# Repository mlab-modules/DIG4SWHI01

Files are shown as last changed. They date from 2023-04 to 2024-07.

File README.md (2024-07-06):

# DIG4SWHI01A - quad channel current sensing high-side switch

Switch for voltage from 4 V to 28 V. Resistance in spliced state 50 mOhm. Integrated circuit [VNQ7050AJ](https://www.st.com/en/automotive-analog-and-power/vnq7050aj.html).

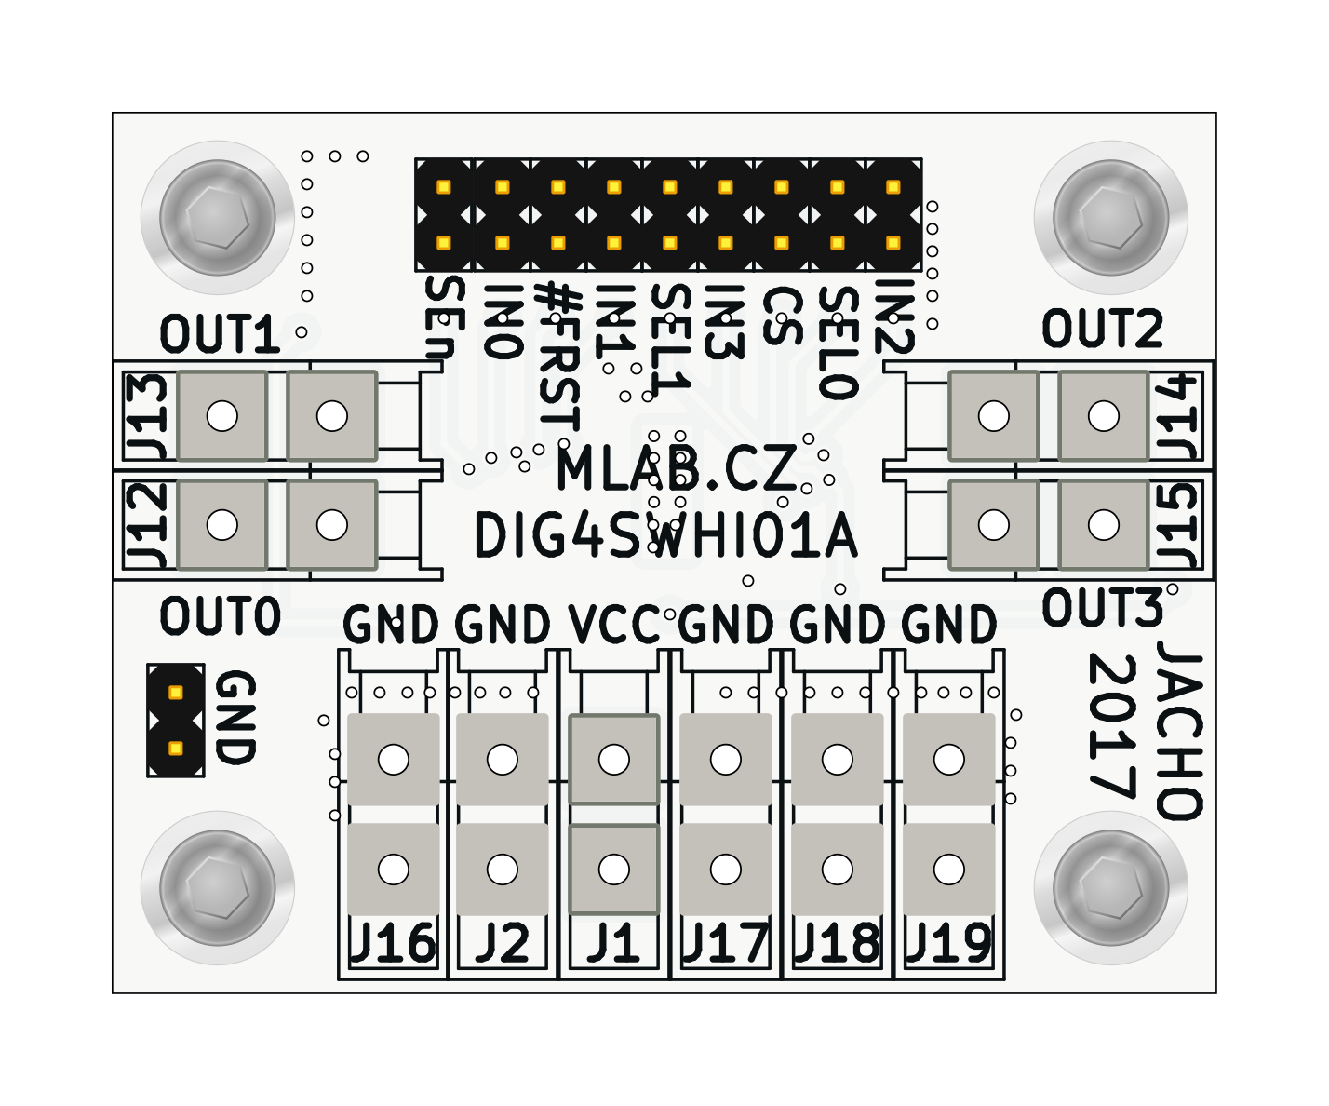
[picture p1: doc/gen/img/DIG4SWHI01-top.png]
DIG4SWHI01A

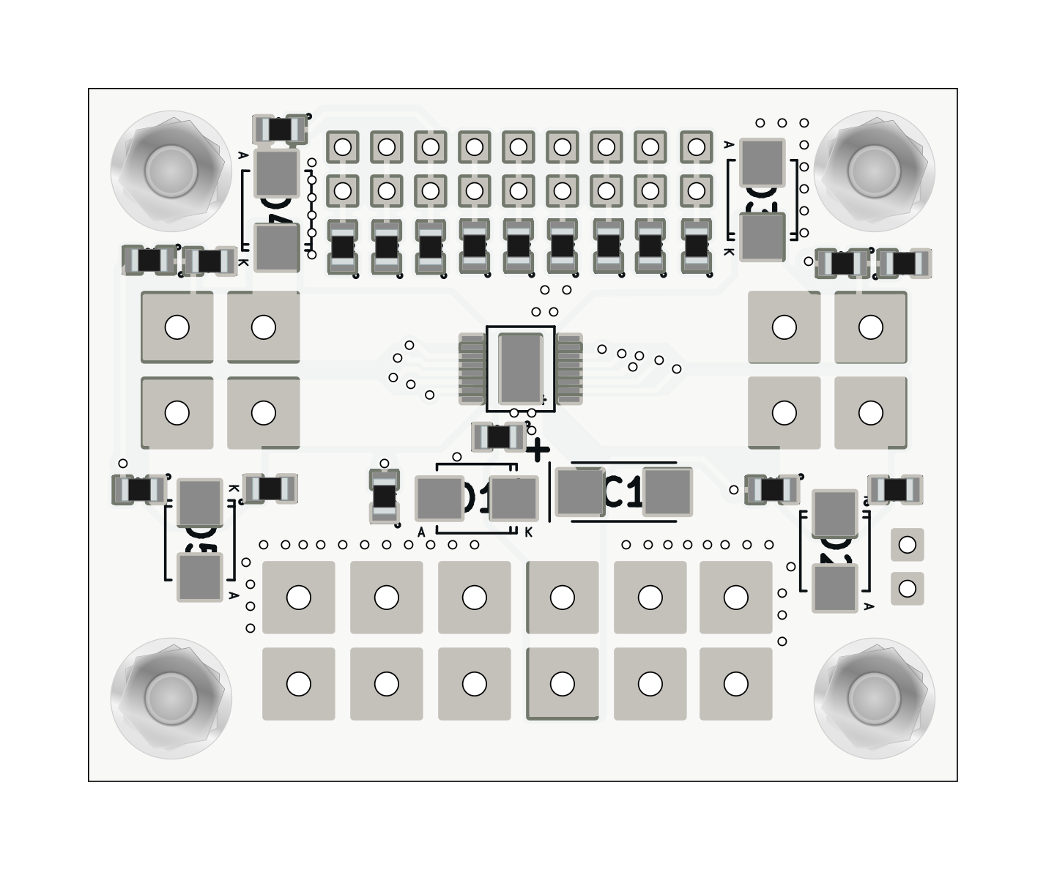
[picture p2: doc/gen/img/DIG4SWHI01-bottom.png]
DIG4SWHI01A


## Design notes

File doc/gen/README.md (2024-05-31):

# PCB

Board size: 50.29x40.13 mm (1.98x1.58 inches)

- This is the size of the rectangle that contains the board
- Thickness: 1.6 mm (63 mils)
- Material: FR4
- Finish: HAL
- Layers: 2
- Copper thickness: 35 µm

Solder mask: TOP / BOTTOM

- Color: Green

Silk screen: TOP / BOTTOM

- Color: White

# Important sizes

Clearance: 0.2 mm (8 mils)

Track width: 0.25 mm (10 mils)

- By design rules: 0.2 mm (8 mils)

Drill: 0.5 mm (20 mils)

- Vias: 0.5 mm (20 mils) [Design: 0.4 mm (16 mils)]
- Pads: 0.5 mm (20 mils)
- The above values are real drill sizes, they add 0.1 mm (4 mils) to plated holes (PTH)

Via: 0.8/0.4 mm (31/16 mils)

- By design rules: 0.4/0.3 mm (16/12 mils)
- Micro via: yes [0.2/0.1 mm (8/4 mils)]
- Buried/blind via: yes
- Total: 74 (thru: 74 buried/blind: 0 micro: 0)

Outer Annular Ring: 0.15 mm (6 mils)

- By design rules: 0.26 mm (10 mils)

Eurocircuits class: 4B
- Using min drill 0.5 mm for an OAR of 0.15 mm

# General stats

Components count: (SMD/THT)

- Top: 0/24 (THT)
- Bottom: 26/1 (SMD + THT)

Defined tracks:

- 0.3 mm (12 mils)
- 0.4 mm (16 mils)
- 0.5 mm (20 mils)
- 0.6 mm (24 mils)
- 0.8 mm (31 mils)
- 1.0 mm (39 mils)

Used tracks:

- 0.25 mm (10 mils) (76) defined: no
- 0.3 mm (12 mils) (139) defined: yes

Defined vias:

Used vias:

- 0.8/0.4 mm (31/16 mils) (Count: 74, Aspect: 2.0 A) defined: no

Holes (excluding vias):

- 0.4 mm (16 mils) (8)
- 0.89 mm (35 mils) (20)
- 1.3 mm (51 mils) (20)
- 3.0 mm (118 mils) (4)

Oval holes:

Drill tools (including vias and computing adjusts and rounding):

- 0.5 mm (20 mils) (82)
- 1.0 mm (39 mils) (20)
- 1.4 mm (55 mils) (20)
- 3.1 mm (122 mils) (4)

Solder paste stats:

Using a paste with 87.75 % alloy, that has an specific gravity for the alloy of 7.4 g/cm³
and 1.0 g/cm³ for the flux. This paste has an specific gravity of  4.15 g/cm³.

The stencil thickness is  0.12 mm.

| Side | Pads with paste | Area [mm²] | Paste [g] |
|---|---|---|---|
| Total  | 69 | 134.06 | 0.67 |

Note: this is just an approximation to the theoretical value. Margins of the solder mask and waste aren't computed.

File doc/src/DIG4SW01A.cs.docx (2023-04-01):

Plný H-můstek s proudovou ochranou

Jan Chroust

## Základem modulu je integrovaný obvod DRV8871, který umožňuje řízení zátěže špičkově až do 3,6 A při napětích v rozsahu 6,5 V – 45 V. Externím odporem je možné nastavit maximální proud.

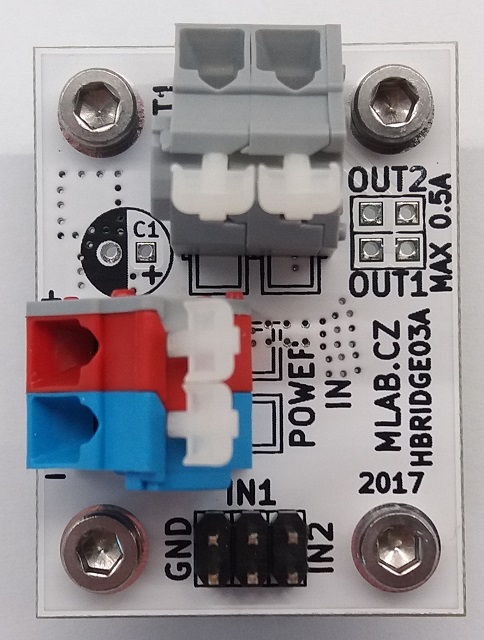
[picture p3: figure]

# 1. Technické parametry

Parametr | Hodnota | Poznámka
Napájení | 6,5 V – 45 V
Proud | Max 3,6A | Špičkově
Integrovaný obvod | DRV8871
Hlavní využití | H-můstek
Rozměry | 40.13 x 30.00 x 16 mm | Výška nad základní deskou

# 2. Popis konstrukce

Modul je napájen přes Wago svorky označené POWER IN. Pro zapojení zátěže je možné si vybrat mezi svorkovnicí Wago, nebo hřebínkem. Při využití hřebínku by zátěž neměla překročit odběr 0,5 A.

Rezistorem R1 je možné provést nastavení maximálního proudu.

I_(MAX) =64/(R1 (kOhm)) (A)

Ovládání režimu můstku se provádí přes piny IN1 a IN2. Odpory R2 a R3 tvoří pull-down pro tyto vstupy. IO obsahuje vnitřní pull-down rezistory, proto tyto pozice není potřeba standardně osazovat.

Tabulka režimů:

IN1 | IN2 | OUT1 | OUT2
0 | 0 | Vysoká Z | Vysoká Z | Po 1ms spánkový režim
0 | 1 | L | H | I OUT2->OUT1
1 | 0 | H | L | I OUT1->OUT2
1 | 1 | L | L | Brždění

## 2.1. Schéma

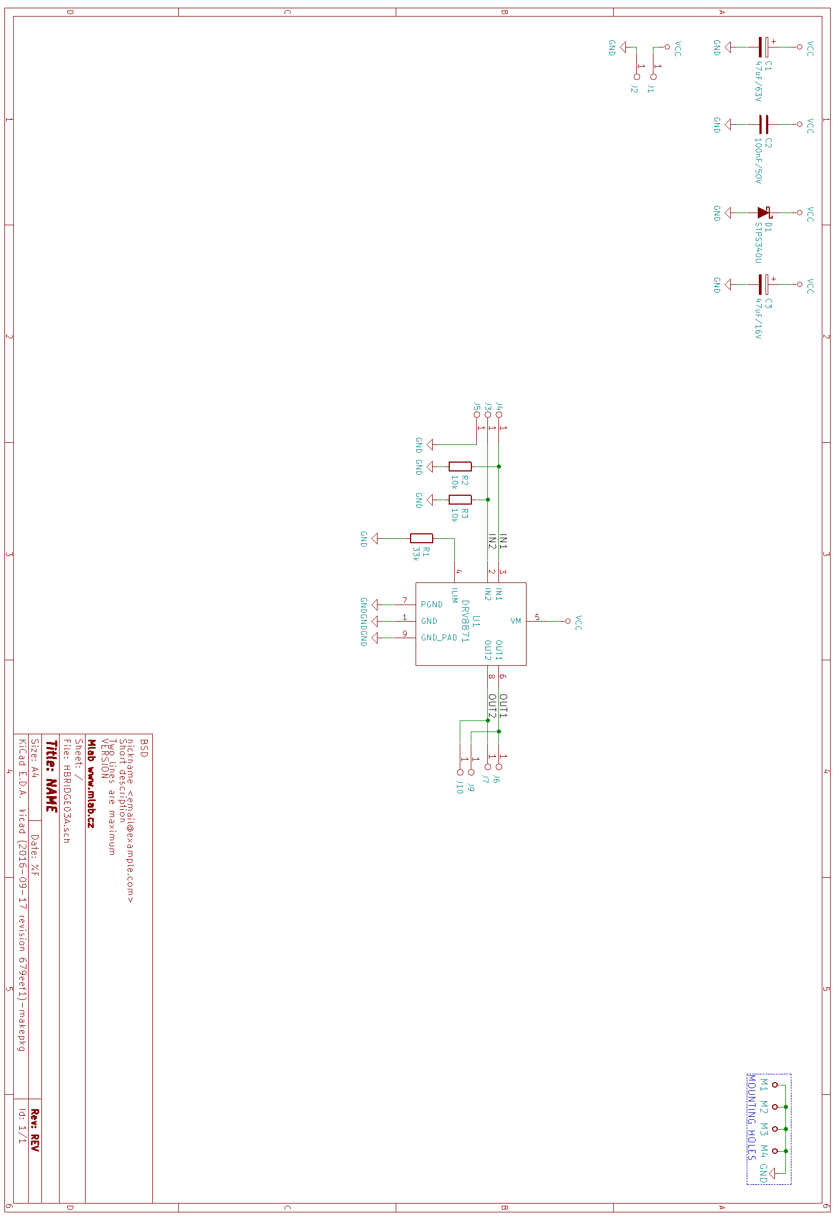
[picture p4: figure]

# 3. Osazení a oživení

## 3.1. Osazení

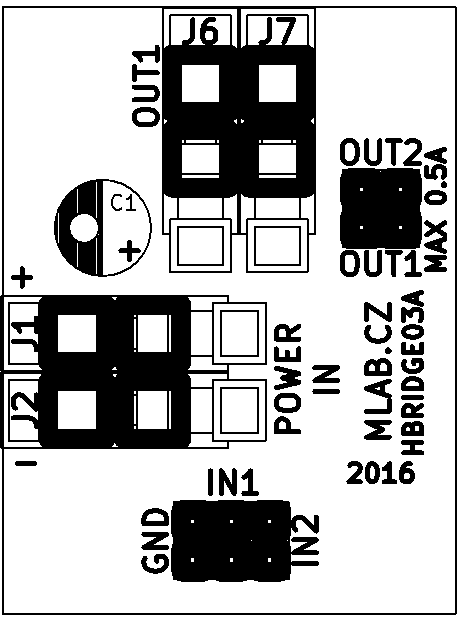
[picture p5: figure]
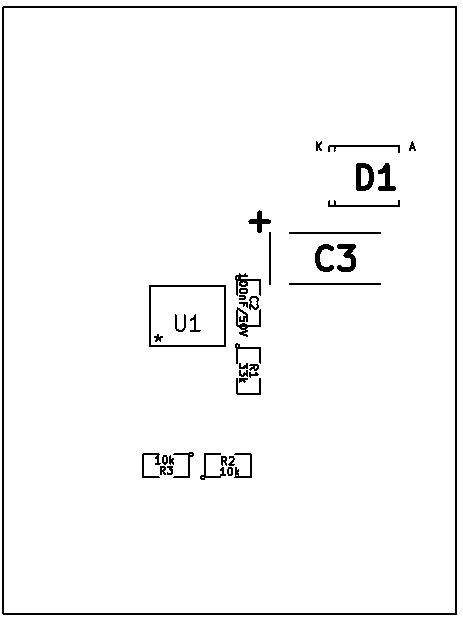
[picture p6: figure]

Označení | Typ | Pouzdro | Počet
U1 | DRV8871 | HSOP-8 | 1
C2 | 100nF/50V | SMD-0805 | 1
C3 | 47uF/16V | TantalC_SizeC_Reflow | 1
D1 | STPS340U | Diode-SMB_Standard | 1
J1,J2,J6,J7 | CONN1_1 | WAGO256 | 4
J3,J4,J5,J9,J10 | JUMP_2x1 | Straight_2x01 | 5
M1,M2,M3,M4 | HOLE | MountingHole_3mm | 4
R1 | 33k | SMD-0805 | 1
C1 | 47uF/63V | C_Radial_D6.3_L11.2_P2.5 | 1
R2,R3 | nic | SMD-0805 | 2

## 3.2. Oživení

Po osazení modulu je dobré provést vizuální kontrolu, případně proměřit, zda na napájení není zkrat. Další oživení není potřeba.

HBRIDGE03A / 2017-05-09 / jacho/ http://www.mlab.cz 4 / 4

HBRIDGE03A MLAB

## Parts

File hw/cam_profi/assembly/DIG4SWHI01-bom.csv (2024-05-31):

Component | Description | Part | References | Value | Footprint | Quantity Per PCB | Datasheet
1 |  | C | C3 | 100pF | SMD-0805 | 1
2 |  | C | C4C5C6C7 | 10nF | SMD-0805 | 4
3 |  | C | C2 | 100nF | SMD-0805 | 1
4 |  | CP | C1 | 47uF/16V | TantalC_SizeC_Reflow | 1
5 |  | D_Schottky | D1 | SMBJ15A-E3/52 | Diode-SMB_Standard | 1
6 |  | D_ZENER | D2D3D4D5 | SMBJ15A-E3/52 | SMB_Standard | 4
7 |  | CONN1_1 | J1J2J12J13J14J15J16J17J18J19 | CONN1_1 | WAGO256_2 | 10
8 |  | JUMP_2x1 | J3J4J5J6J7J8J9J10J11J20 | JUMP_2x1 | Straight_2x01 | 10
9 |  | R | R2 | 510 | SMD-0805 | 1
10 |  | R | R1R3R4R5R6R7R8R9R10 | 10k | SMD-0805 | 9
11 |  | R | R11R12R13R14 | 20k | SMD-0805 | 4
12 |  | VNQ7050AJ | U1 | VNQ7050AJ | PowerSSO-16 | 1

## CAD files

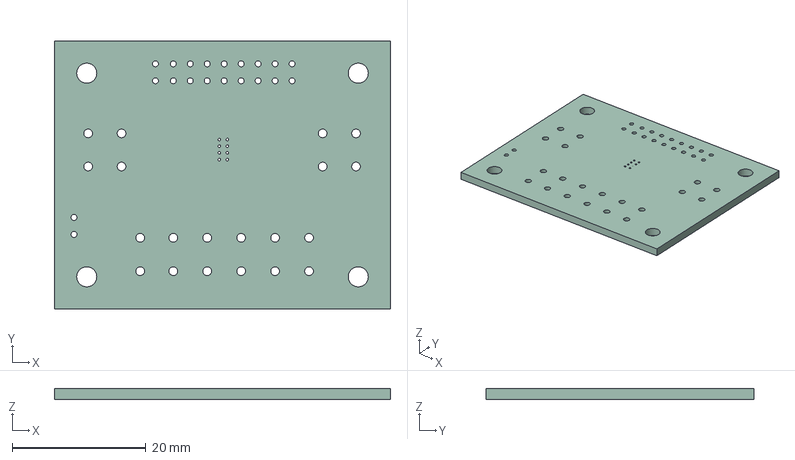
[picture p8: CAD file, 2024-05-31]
doc/gen/DIG4SWHI01.step
50.3 x 40.1 x 1.60 mm

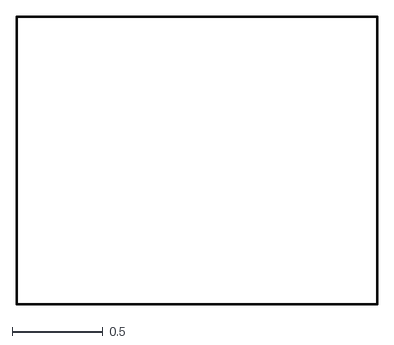
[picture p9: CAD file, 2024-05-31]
doc/gen/dxf/DIG4SWHI01-Edge_Cuts.dxf
1.99 x 1.59

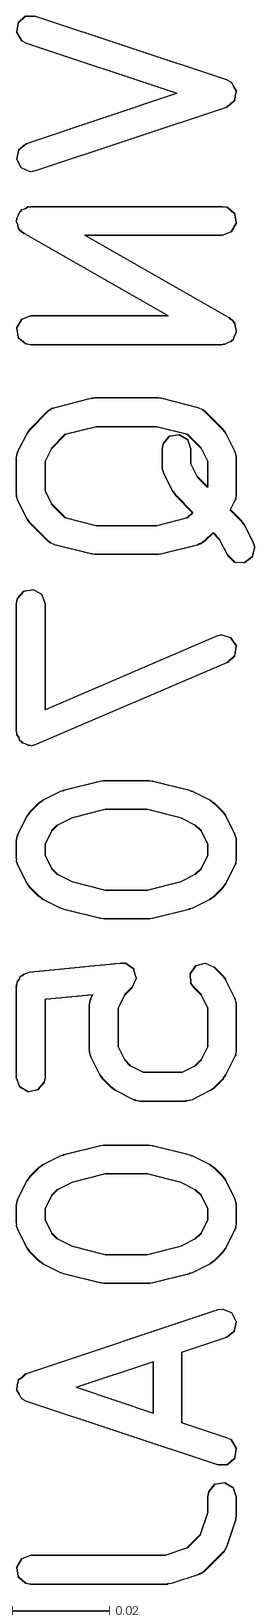
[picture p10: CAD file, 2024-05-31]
doc/gen/dxf/DIG4SWHI01-B_Fab.dxf
0.049 x 0.323

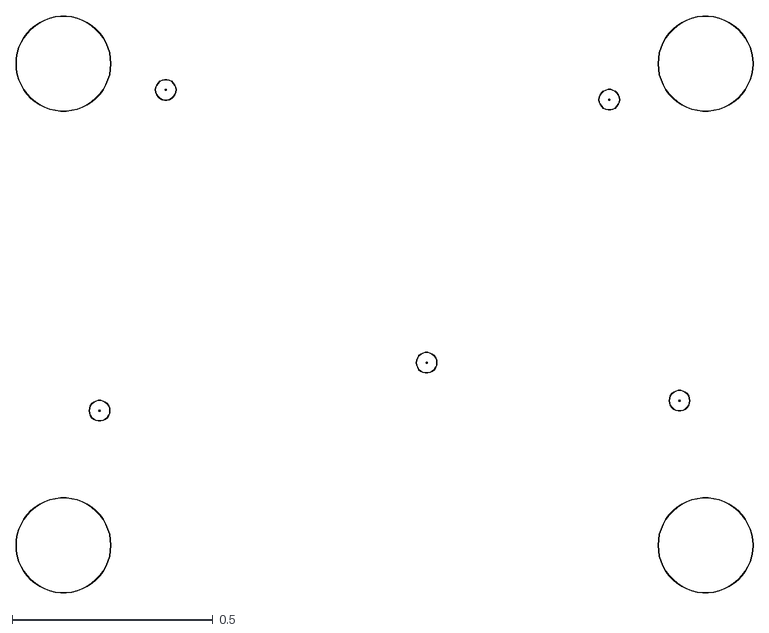
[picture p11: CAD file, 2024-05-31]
doc/gen/dxf/DIG4SWHI01-B_Adhesive.dxf
1.84 x 1.44

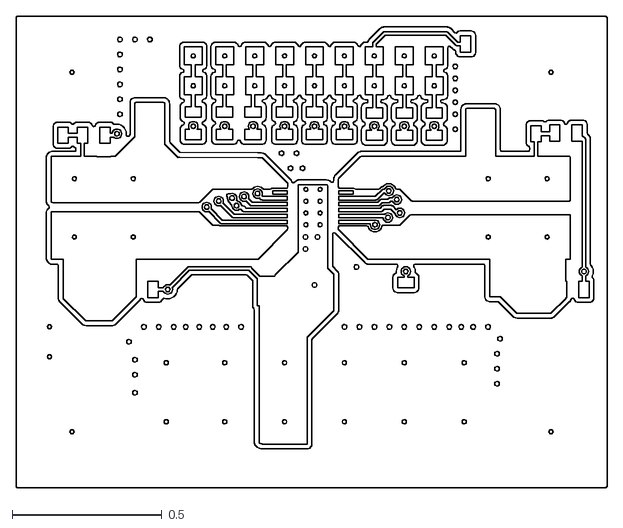
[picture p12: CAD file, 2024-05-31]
doc/gen/dxf/DIG4SWHI01-B_Cu.dxf
1.97 x 1.57

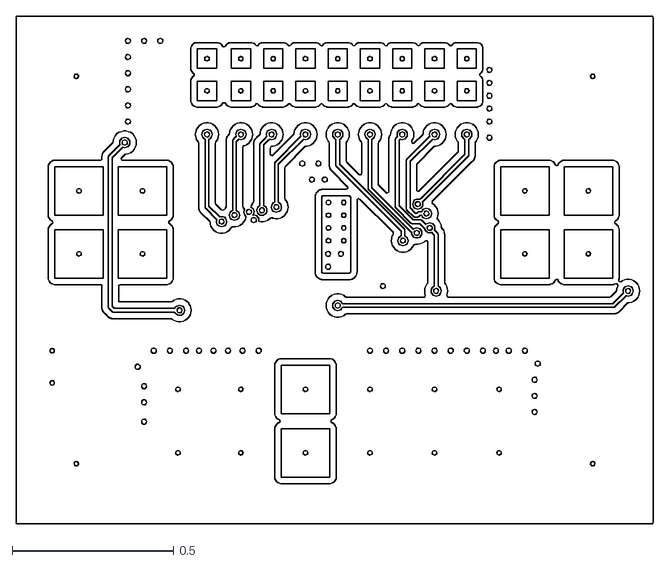
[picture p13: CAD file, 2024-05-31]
doc/gen/dxf/DIG4SWHI01-F_Cu.dxf
1.97 x 1.57

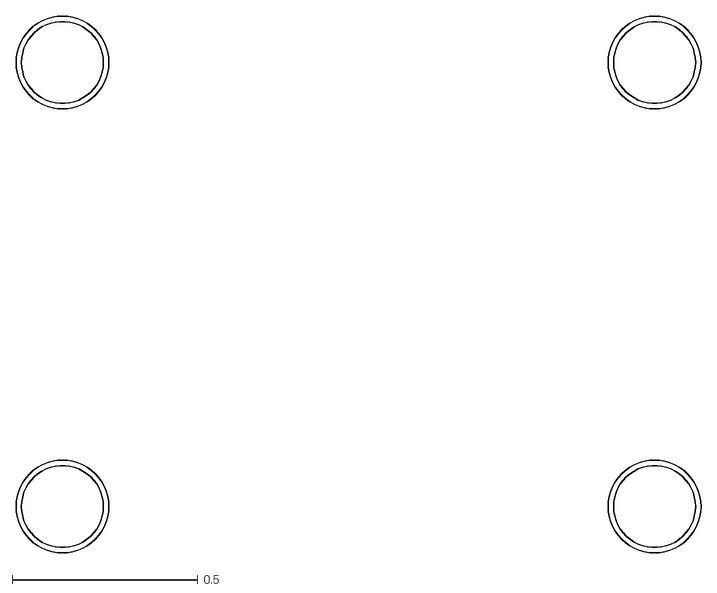
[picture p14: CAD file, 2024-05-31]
doc/gen/dxf/DIG4SWHI01-User_Comments.dxf
1.85 x 1.45

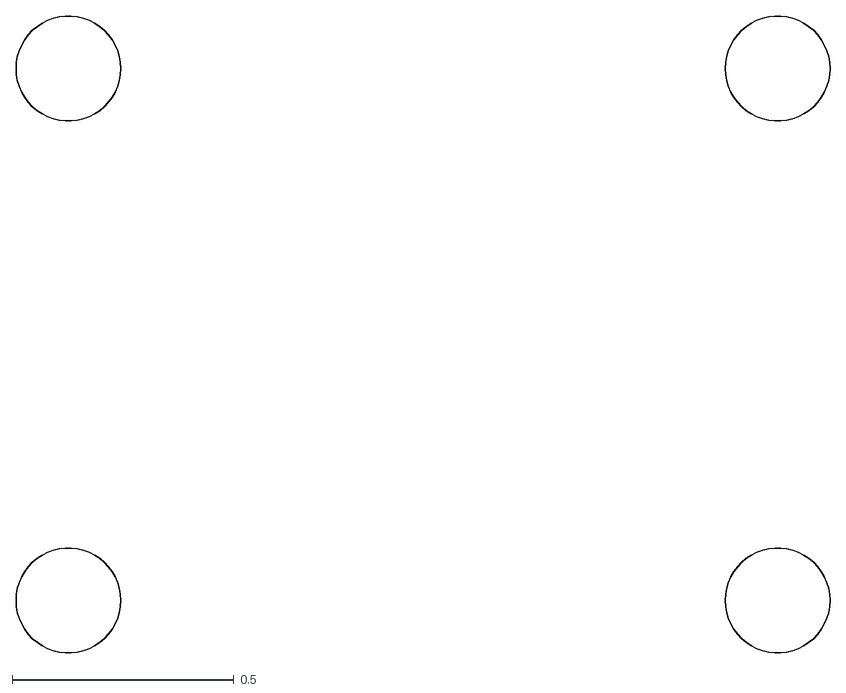
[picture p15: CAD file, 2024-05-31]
doc/gen/dxf/DIG4SWHI01-F_Adhesive.dxf
1.84 x 1.44

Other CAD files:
doc/gen/dxf/DIG4SWHI01-B_Courtyard.dxf
doc/gen/dxf/DIG4SWHI01-F_Fab.dxf
doc/gen/dxf/DIG4SWHI01-User_Eco1.dxf
doc/gen/dxf/DIG4SWHI01-User_Drawings.dxf
doc/gen/dxf/DIG4SWHI01-User_Eco2.dxf
doc/gen/dxf/DIG4SWHI01-Margin.dxf
doc/gen/dxf/DIG4SWHI01-F_Courtyard.dxf
doc/gen/dxf/DIG4SWHI01-B_Mask.dxf
doc/gen/dxf/DIG4SWHI01-B_Paste.dxf
doc/gen/dxf/DIG4SWHI01-B_Silkscreen.dxf
doc/gen/dxf/DIG4SWHI01-F_Mask.dxf
doc/gen/dxf/DIG4SWHI01-F_Paste.dxf
doc/gen/dxf/DIG4SWHI01-F_Silkscreen.dxf

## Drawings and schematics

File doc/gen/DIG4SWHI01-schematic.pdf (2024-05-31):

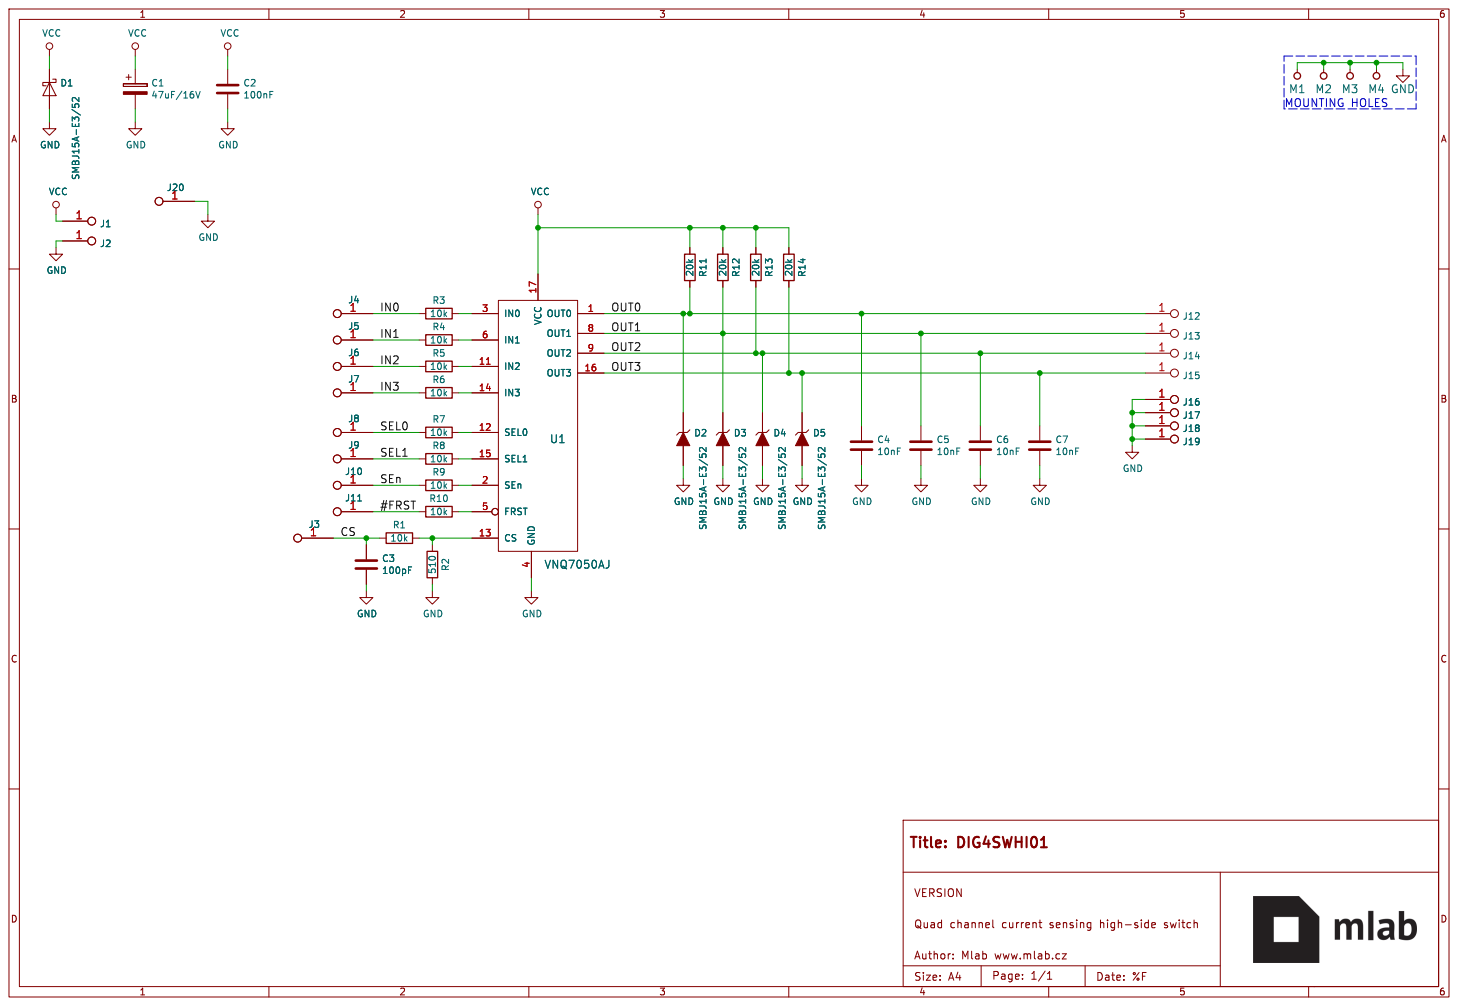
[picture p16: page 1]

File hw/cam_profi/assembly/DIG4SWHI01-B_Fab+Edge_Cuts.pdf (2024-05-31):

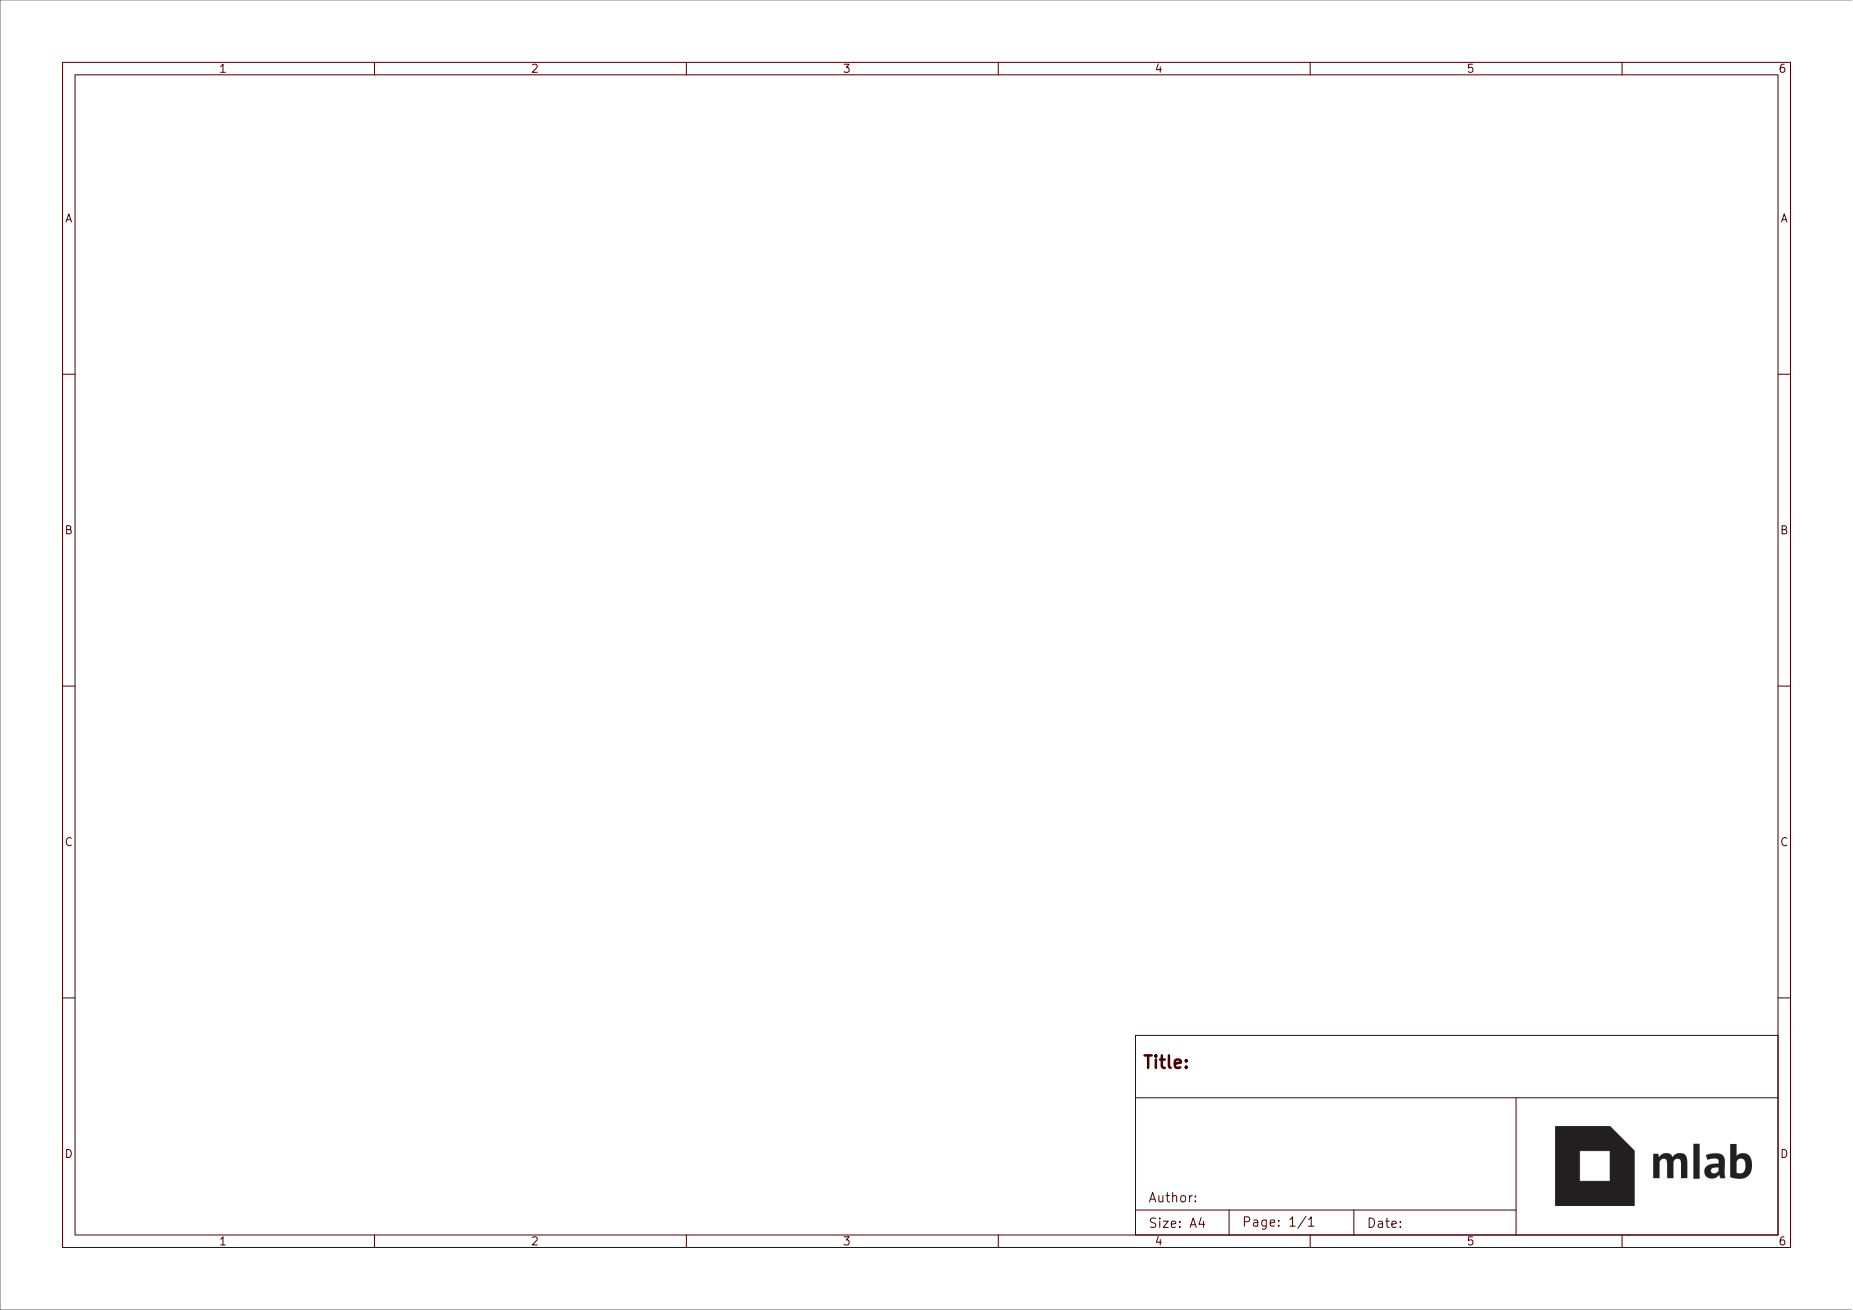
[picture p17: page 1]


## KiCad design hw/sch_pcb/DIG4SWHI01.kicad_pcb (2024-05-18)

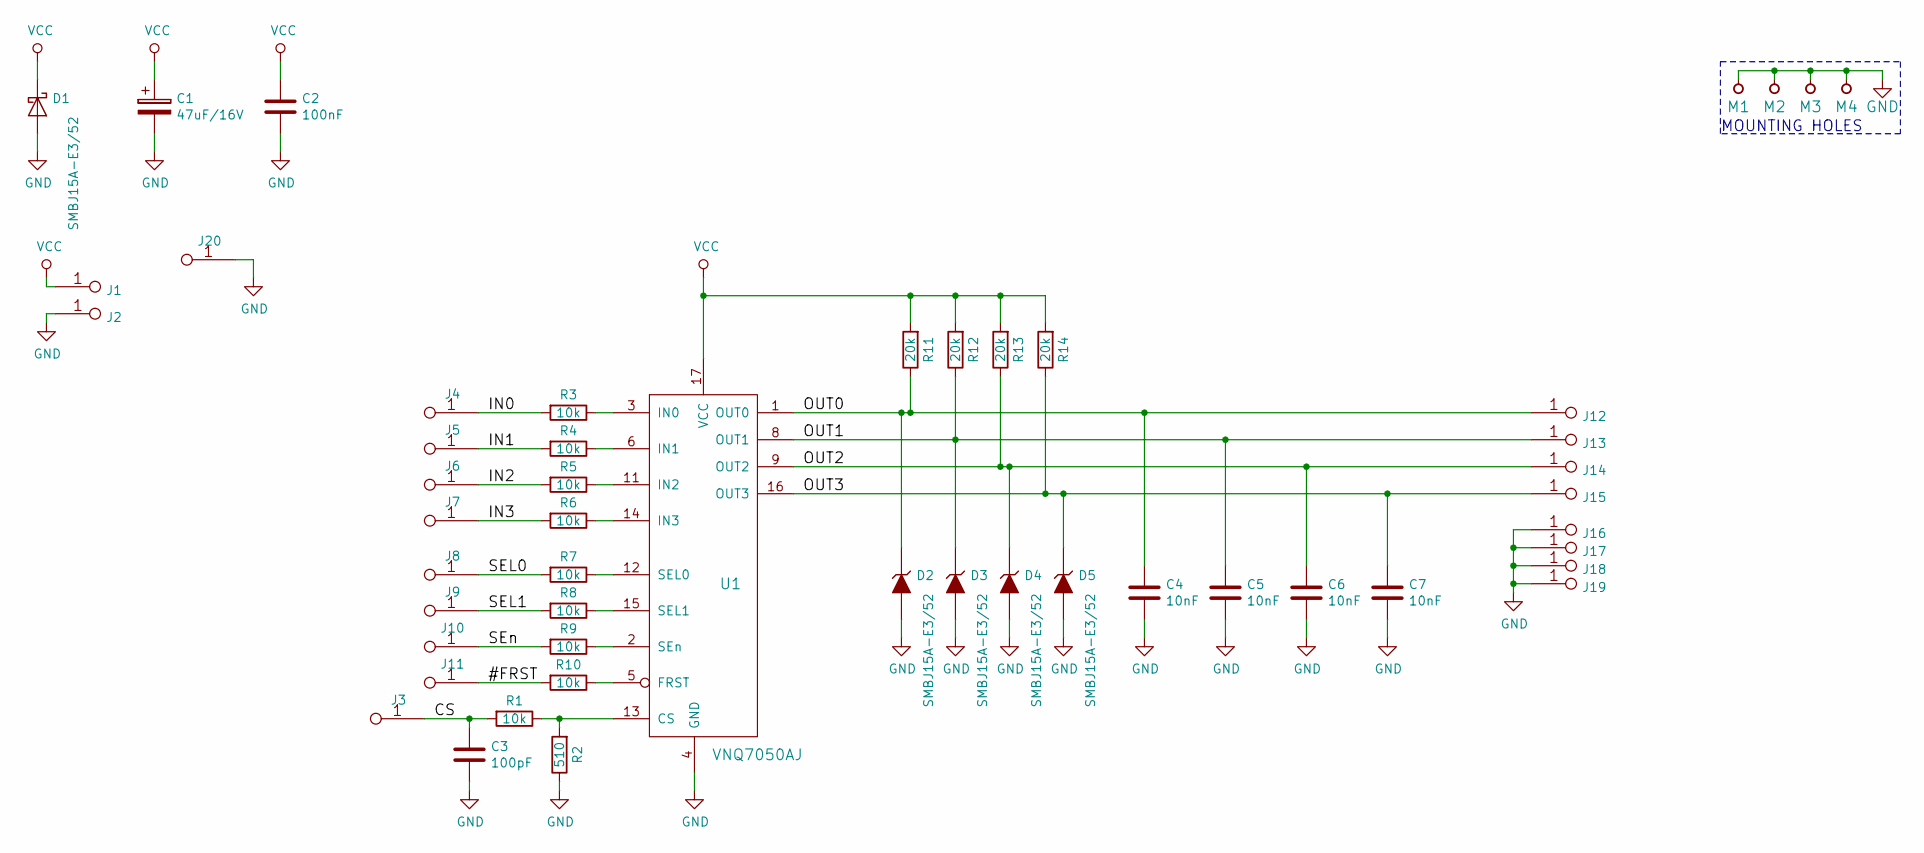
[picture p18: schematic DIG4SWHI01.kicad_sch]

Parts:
C1: 47uF/16V; TantalC_SizeC_Reflow
C2: 100nF; SMD-0805
C3: 100pF; SMD-0805
C4, C5, C6, C7: 10nF; SMD-0805
D1: SMBJ15A-E3/52; Diode-SMB_Standard
D2, D3, D4, D5: SMBJ15A-E3/52; SMB_Standard
J1, J2, J12, J13, J14, J15, J16, J17, J18, J19: CONN1_1; WAGO256_2
J3, J4, J5, J6, J7, J8, J9, J10, J11, J20: JUMP_2x1; Straight_2x01
M1, M2, M3, M4: HOLE; MountingHole_3mm
R1, R3, R4, R5, R6, R7, R8, R9, R10: 10k; SMD-0805
R2: 510; SMD-0805
R11, R12, R13, R14: 20k; SMD-0805
U1: VNQ7050AJ; PowerSSO-16

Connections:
/#FRST: J11.1, J11.2 (1), R10.2
/CS: C3.1, J3.1, J3.2 (1), R1.2
/IN0: J4.1, J4.2 (1), R3.2
/IN1: J5.1, J5.2 (1), R4.2
/IN2: J6.1, J6.2 (1), R5.2
/IN3: J7.1, J7.2 (1), R6.2
/OUT0: C4.1, D2.1 (K), J12.1, R11.1, U1.1 (OUT0)
/OUT1: C5.1, D3.1 (K), J13.1, R12.1, U1.8 (OUT1)
/OUT2: C6.1, D4.1 (K), J14.1, R13.1, U1.9 (OUT2)
/OUT3: C7.1, D5.1 (K), J15.1, R14.1, U1.16 (OUT3)
/SEL0: J8.1, J8.2 (1), R7.2
/SEL1: J9.1, J9.2 (1), R8.2
/SEn: J10.1, J10.2 (1), R9.2
GND: C1.2, C2.2, C3.2, C4.2, C5.2, C6.2, C7.2, D1.2 (A), D2.2 (A), D3.2 (A), D4.2 (A), D5.2 (A), J2.1, J16.1, J17.1, J18.1, J19.1, J20.1, J20.2 (1), M1.1, M2.1, M3.1, M4.1, R2.1, U1.4 (GND)
unnamed: R1.1, R2.2, U1.13 (CS)
unnamed: R10.1, U1.5 (FRST)
unnamed: R3.1, U1.3 (IN0)
unnamed: R4.1, U1.6 (IN1)
unnamed: R5.1, U1.11 (IN2)
unnamed: R6.1, U1.14 (IN3)
unnamed: R7.1, U1.12 (SEL0)
unnamed: R8.1, U1.15 (SEL1)
unnamed: R9.1, U1.2 (SEn)
VCC: C1.1, C2.1, D1.1 (K), J1.1, R11.2, R12.2, R13.2, R14.2, U1.17 (VCC)

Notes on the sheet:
MOUNTING HOLES

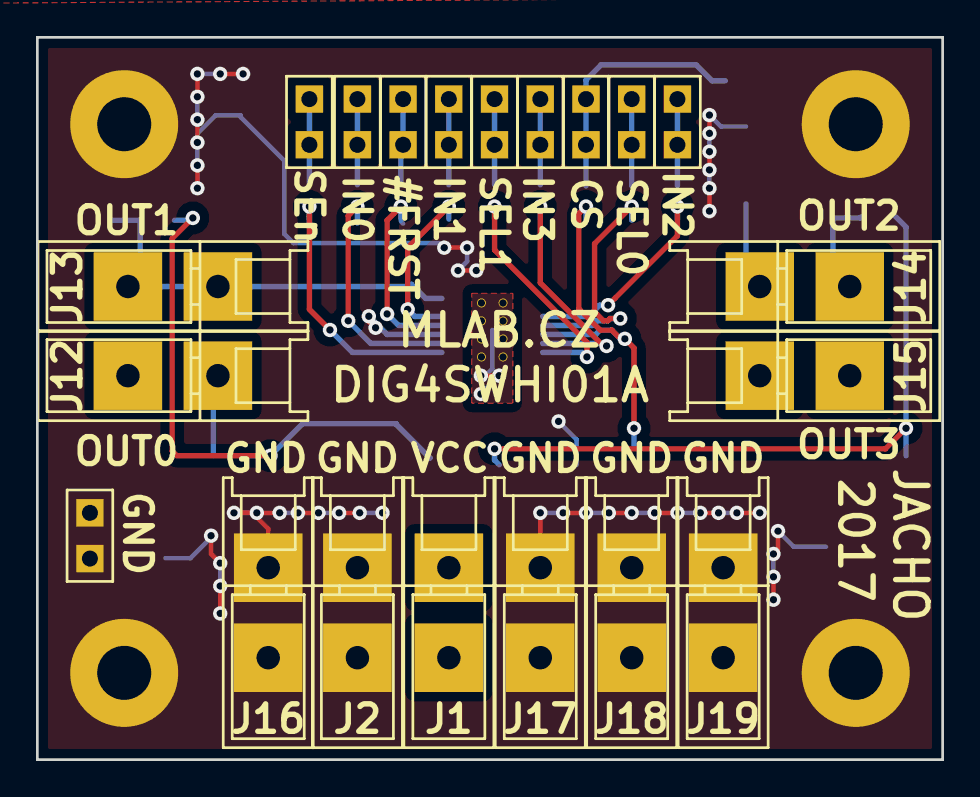
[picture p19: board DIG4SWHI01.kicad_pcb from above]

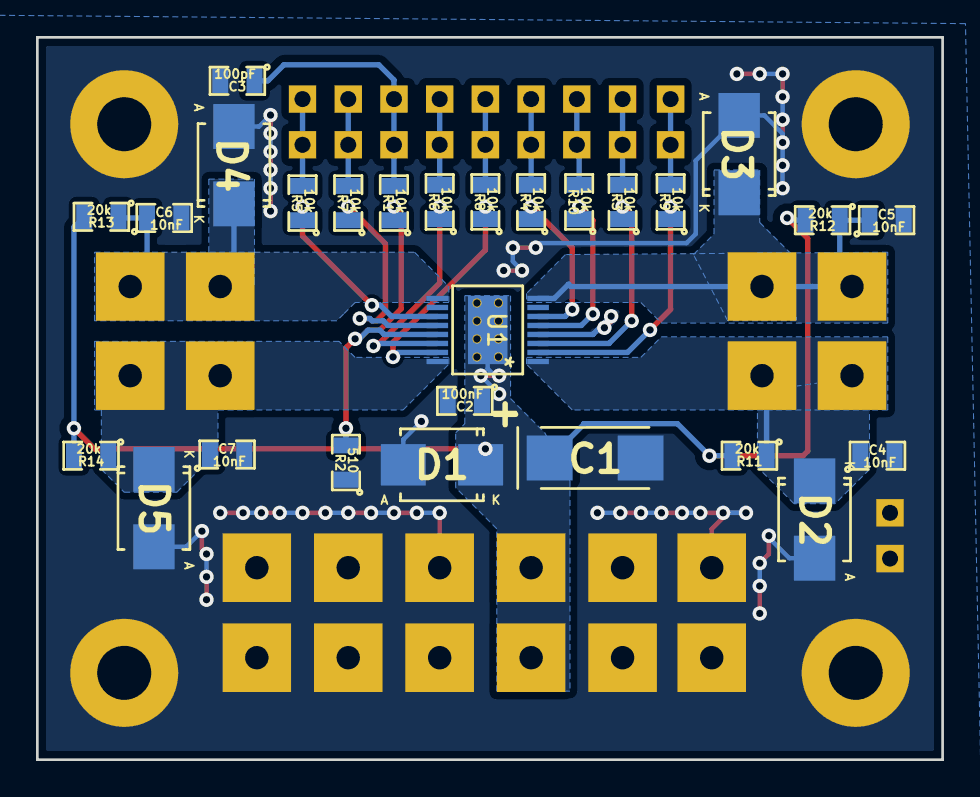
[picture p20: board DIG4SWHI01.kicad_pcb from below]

Board: 2 copper layers, 50.3 x 40.1 mm, 51 parts (27 on the bottom side), 24 nets.

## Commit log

2023-04-01 Adding force option to enable splitting in not fresh copy of Modules repository.
    [DIG4SWHI01A.csv, DIG4SWHI01A.kicad_pcb, DIG4SWHI01A.sch]
2024-05-18 Update project according to actual MLAB standard.
    [DIG4SWHI01.kicad_pcb, DIG4SWHI01.kicad_sch, DIG4SWHI01A.csv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]
2024-05-18 Attempt to resolve action fail.
    [DIG4SWHI01.kicad_pcb, DIG4SWHI01.kicad_sch]
2024-05-31 Update actions products
    [DIG4SWHI01-B_Adhesive.dxf, DIG4SWHI01-B_Courtyard.dxf, DIG4SWHI01-B_Cu.dxf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]
